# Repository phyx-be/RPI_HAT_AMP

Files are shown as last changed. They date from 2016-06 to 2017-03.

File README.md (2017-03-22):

# RPI HAT AMP TAS5756
A Class-D amplifier for your Raspberry Pi

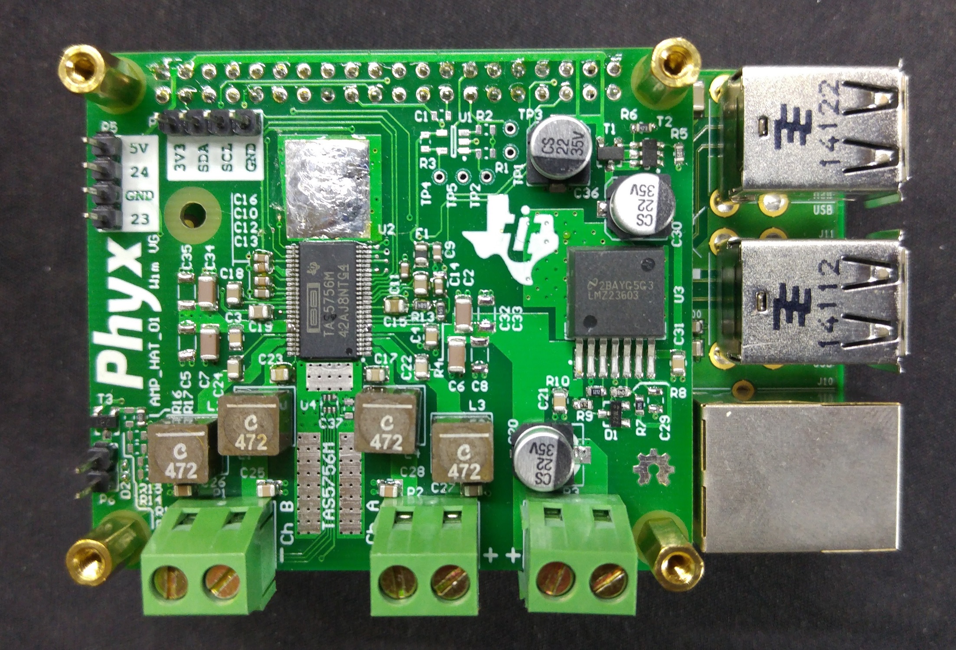
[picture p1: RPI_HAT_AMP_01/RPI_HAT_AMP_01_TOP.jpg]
Assembled image


## Rev 02

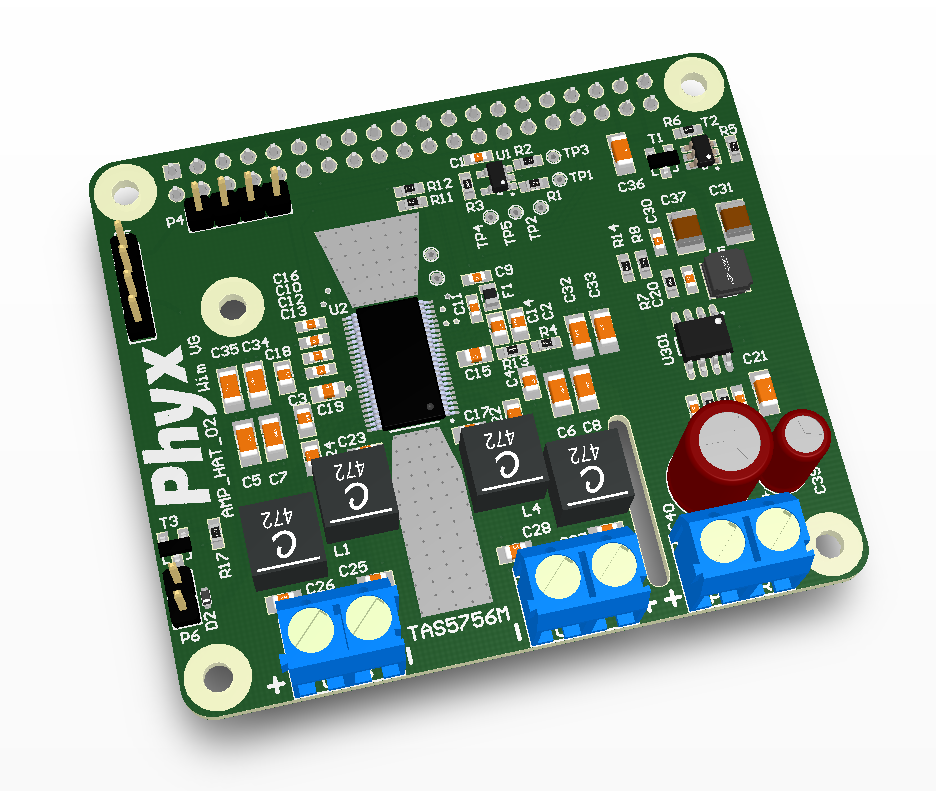
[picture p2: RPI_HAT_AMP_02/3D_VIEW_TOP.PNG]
RPI_HAT_AMP_02_TOP

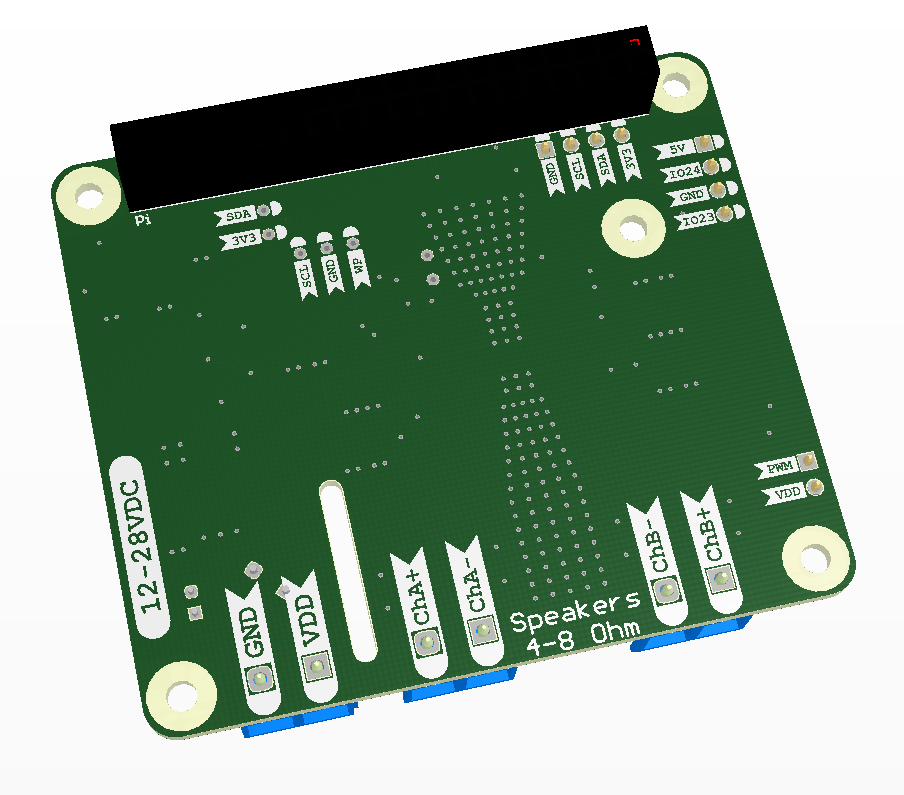
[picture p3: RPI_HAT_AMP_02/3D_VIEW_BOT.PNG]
RPI_HAT_AMP_02_BOT


Revision 02 has been updated with a [cheaper power supply](http://www.richtek.com/assets/product_file/RT7272A/DS7272A-04.pdf) with a wide input range.

## Rev 01

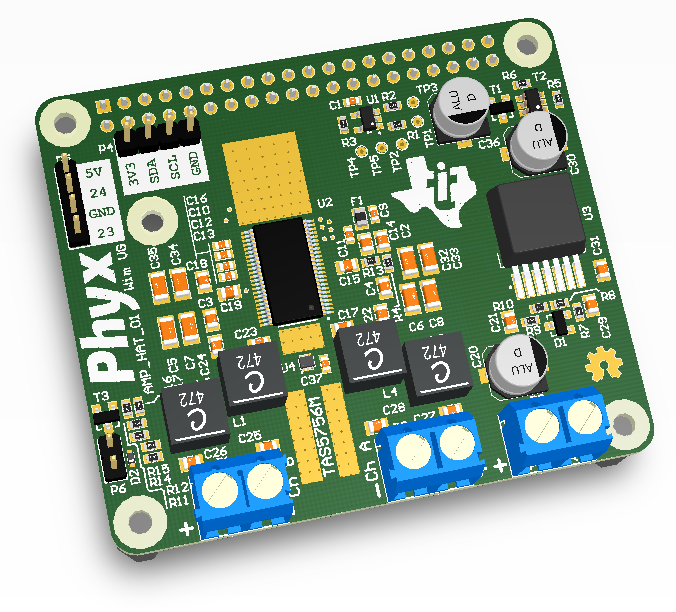
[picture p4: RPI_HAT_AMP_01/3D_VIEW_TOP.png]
RPI_HAT_AMP_01_TOP

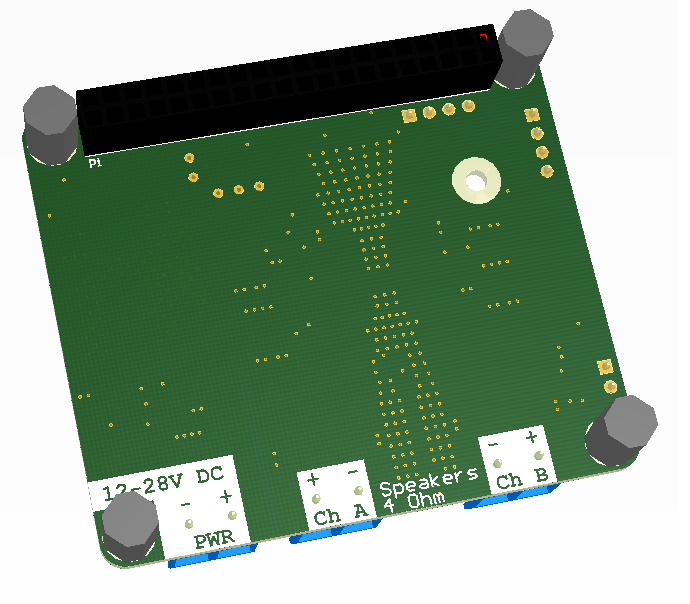
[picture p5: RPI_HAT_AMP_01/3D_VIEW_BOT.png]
RPI_HAT_AMP_01_BOT


The board is designed around the Ti [TAS5756](http://www.ti.com/product/TAS5756) Class D amplifier. It also features an I2C EEPROM, Ti [TMP112](http://www.ti.com/product/tmp112) I2C temperature sensor, some useful IO connectores, a FET connected to a PWM ouput and a Ti [LMZ23603](http://www.ti.com/product/LMZ23603) Simple Switcher module capable of providing 3A on the 5V rail.

### Possible improvements

- Cheaper Power supply
- Cheaper Inductors

## Setup your RPi

For our setup we use [Volumio](https://volumio.org) coupled with a little bit of Pyhton code to run everything. First things first, get yourself a running [Volumio](https://volumio.org) system by following [their manual](https://volumio.org/get-started/). Once the board is up and running you can start the configuration needed for the amplifier.
- Make sure your system is up to date by running `sudo rpi-update`
- Ensure the drivers are loaded by adding `dtoverlay=iqaudio-dacplus` in the `/boot/config.txt` file
- Remove the standard Raspberry Pi audio card by commecinting out the `snd-bcm2835` entry in the file `/etc/modules`, you might want to add `i2c-dev` as well.
- Sync and reboot your system wiht `sync` and `duso reboot`
- Verify your card is available to ALSO by running `aplay -l`
- Set the volume to 100% using `alsamixer`, both _ANALOGUE_ and _ANALOGUE PLAYBACK BOOST_ should be set to 100%
- Automaticly unmute the amplifier om boot by adding the following lines to `/etc/rc.local` right before `exit(0)`
```
#Unmute the AMP
echo "17" > /sys/class/gpio/export
echo "out" >/sys/class/gpio/gpio17/direction
echo "1" >/sys/class/gpio/gpio17/value
```
- Since the 5V power source is able to provide more than sufficient power to the board, you can increase the USB current of the Raspberry Pi. This can be done by adding `max_usb_current=1` to the `/boot/config.txt` file.

## Optional IO expansion

You can stack a PCB on the anplifier with 16 extra IO pins. This board is based on the [MCP23017](http://www.microchip.com/MCP23017) which is a 16 bits I2C IO expander. It has native support in [Wiring Pi](http://wiringpi.com/extensions/i2c-mcp23008-mcp23017/). You can stack more than one since the expander has multiple address pins. Just make sure you don't use the same address twice.

## Pictures

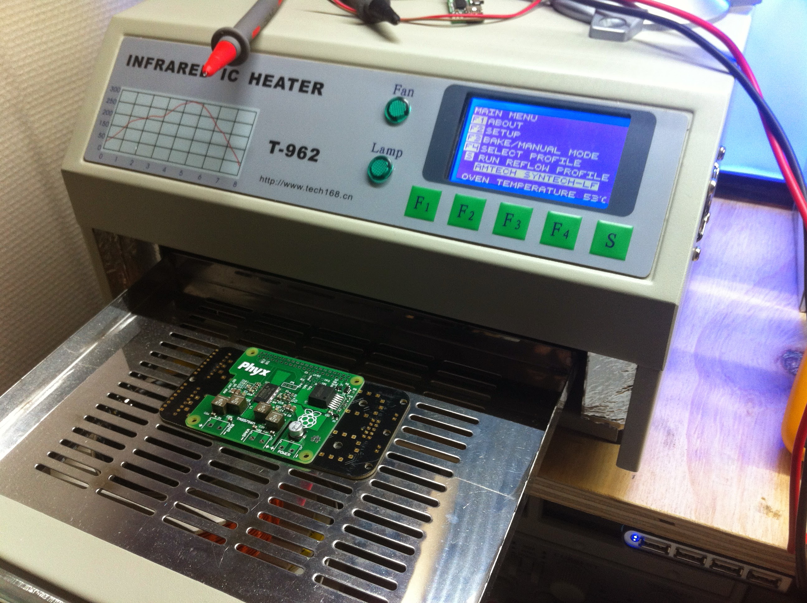
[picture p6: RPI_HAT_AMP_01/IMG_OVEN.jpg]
Oven image

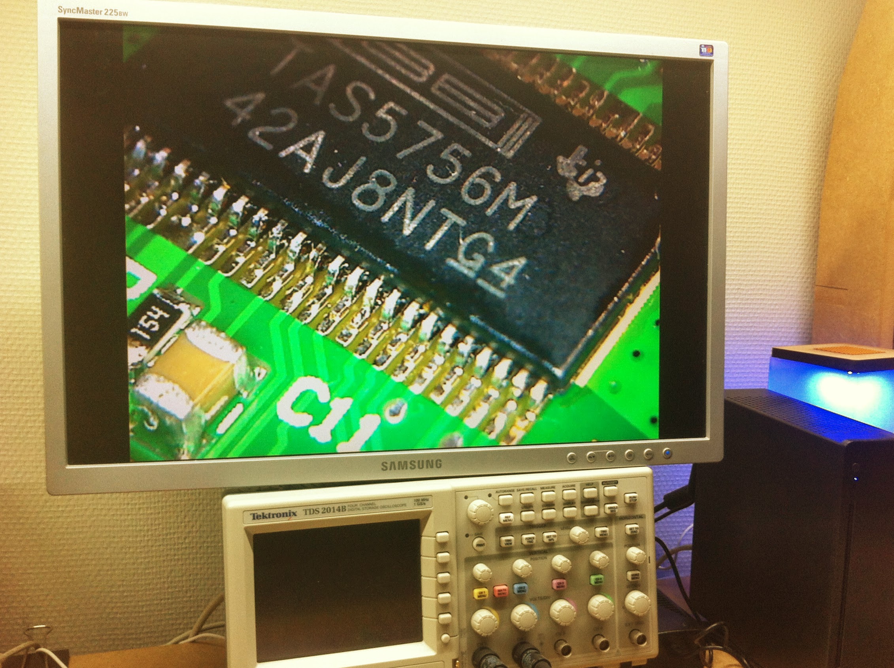
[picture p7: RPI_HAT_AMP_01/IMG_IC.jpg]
IC image


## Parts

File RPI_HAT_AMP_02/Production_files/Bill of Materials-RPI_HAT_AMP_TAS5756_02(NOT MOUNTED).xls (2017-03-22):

Bill of Materials |  |  | TAS5756 HAT
Project: |  | RPI_HAT_AMP_TAS5756_02.PrjPcb
Revision: |  | 02
Variant: |  | NOT MOUNTED
Creation Date: | 22/03/2017 | 20:34:39
Print Date: | 2017-03-22 | 20:36:30
Footprint | Comment | LibRef | Designator | Value | Description | Supplier 1 | Supplier Part Number 1 | Quantity
C0805_N | CAP_CERAMIC | CAP # 1uF 25V 0805 | C2 | 1uF 25V | Capacitor Ceramic | Farnell | 2395779 (https://octopart-clicks.com/click/altium?sku=2395779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) | 1
C0805_N | CAP_CERAMIC | CAP # 100nF 50V 0805 | C3, C4 | 100nF 50V | Capacitor Ceramic | Farnell | 1759265 (https://octopart-clicks.com/click/altium?sku=1759265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) | 2
C1206_N | CAP_CERAMIC | CAP # 22uF 35V 1206 X5R | C5, C6, C7, C8, C32, C33, C34, C35, C36 | 22uF 35V | Capacitor Ceramic | Digikey | 445-8045-1-ND (https://octopart-clicks.com/click/altium?sku=445-8045-1-ND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) | 9
C0603_N | CAP_CERAMIC | CAP # 1uF 16V 0603 | C9, C10, C11, C12, C13, C16 | 1uF 16V | Capacitor Ceramic | Farnell | 2320814 (https://octopart-clicks.com/click/altium?sku=2320814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) | 6
C0805_N | CAP_CERAMIC | CAP # 2u2F 25V 0805 | C14, C15, C18, C19 | 2u2F | Capacitor Ceramic | Farnell | 2320829 (https://octopart-clicks.com/click/altium?sku=2320829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) | 4
C0805_N | CAP_CERAMIC | CAP # 220nF 50V 0805 | C17, C22, C23, C24 | 220nF 50V | Capacitor Ceramic | Farnell | 2320842 (https://octopart-clicks.com/click/altium?sku=2320842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) | 4
C0603_N | CAP_CERAMIC | CAP # 100nF 50V 0603 | C20, C30 | 100nF 50V | Capacitor Ceramic | Farnell | 1759122 (https://octopart-clicks.com/click/altium?sku=1759122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) | 2
C1206_N | CAP_CERAMIC | CAP # 10uF 35V 1206 X5R | C21 | 10uF 35V | Capacitor Ceramic | Farnell | 1797011 (https://octopart-clicks.com/click/altium?sku=1797011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) | 1
C0805_N | CAP_CERAMIC | CAP # 680nF 50V 0805 | C25, C26, C27, C28 | 680nF 50V | Capacitor Ceramic | Farnell | 2210987 (https://octopart-clicks.com/click/altium?sku=2210987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) | 4
C1210_N | CAP_CERAMIC | CAP # 22uF 10V 1210 X5R | C31, C37 | 22uF 10V | Capacitor Ceramic |  |  | 2
C0603_N | CAP_CERAMIC | CAP # 2n7F 25V 0603 | C38 | 2n7F 25V | Capacitor Ceramic |  |  | 1
ON_SOD-523 | NSR0240V2T1G Schottky ULTRAFAST, 200MA, 40V | Schottky NSR0240V2T1G | D2 | NSR0240V2T1G |  | Farnell | 2317403 (https://octopart-clicks.com/click/altium?sku=2317403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) | 1
L0805 | FERRITE | FER # 120R 0.8A 0805 0R12 | F1 | 0.8A 0R12 |  | Farnell | 1669728 (https://octopart-clicks.com/click/altium?sku=1669728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) | 1
XAL6060-472 | XAL6060-472MEC | IND # 4u7H 11A | L1, L2, L3, L4 | 4u7H 11A |  | Farnell | 2289085 (https://octopart-clicks.com/click/altium?sku=2289085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) | 4
SNL_SWPA4020 | SWPA4020S6R8MT | IND # 6u8H SWPA4020 | L5 | 6u8H |  | China | SWPA4020S6R8MT (https://octopart-clicks.com/click/altium?manufacturer=Supplier%20disabled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) | 1
TERM_BLK-0508-2-90 | 2 Way Screw HDR 5,08mm | Terminal Block 5,08mm 2way | P1, P2, P3 | PM5.08/2/90 |  | Farnell |  | 3
HDR1X4 | Header 4 | Pin Header 2.54mm 4way | P5 |  |  |  |  | 1
HDR1X2 | Header 2 | Pin Header 2.54mm 2way | P6 |  |  |  |  | 1
RCPT2X20 | Header 20X2 | Receptable 2.54mm dual row 40way | Pi |  |  |  |  | 1
R0603_N | RESISTOR | RES # 150K 0603 | R4 | 150K |  |  |  | 1
R0603_N | RESISTOR | RES # 10K 0603 | R5 | 10K |  |  |  | 1
R0603_N | RESISTOR | RES # 47K 0603 | R6 | 47K |  |  |  | 1
R0603_N | RESISTOR | RES # 100K 0603 | R7 | 100K |  |  |  | 1
R0603_N | RESISTOR | RES # 62K 0603 | R8 | 62K |  |  |  | 1
R0603_N | RESISTOR | RES # 24K 0603 | R9 | 24K |  |  |  | 1
R0603_N | RESISTOR | RES # 180K 0603 | R10 | 180K |  |  |  | 1
R0603_N | RESISTOR | RES # 680K 0603 | R13 | 680K |  |  |  | 1
R0603_N | RESISTOR | RES # 11K8 0603 | R14 | 11K8 |  |  |  | 1
R0603_N | RESISTOR | RES # 0R 0603 | R17 | 0R |  |  |  | 1
SOT23-3 | 4A P-Ch MOSFET Vgs -4,5 | TSM2311CX P-Ch MOSFET 4A | T1 | TSM2311CX |  | Farnell | 1864586 (https://octopart-clicks.com/click/altium?sku=1864586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) | 1
SOT23-6 | Matched PNP | DMMT5401-7-F matched PNP | T2 | DMMT5401-7-F |  | Farnell | 1773583 (https://octopart-clicks.com/click/altium?sku=1773583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) | 1
SOT23-3 | 2.4A N-Ch MOSFET Vgs 4.5 | ZXMN2B01F N-Ch MOSFET 2.4A 4.5Vgs 30Vds | T3 | ZXMN2B01F |  | Farnell | 1426253 (https://octopart-clicks.com/click/altium?sku=1426253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) | 1
TI-DCA-R-PDSO-G48 | Audio Amp Class D 2ch 2x40W - 1x75W 104SNR | AMP # AUD TAS5756M | U2 | TAS5756M |  |  |  | 1
SOIC_N_8_TH | Buck 3A 36Vin sync | PWR # Buck RT7272A SOP8 | U301 | RT7272AGSP |  | China | RT7272AGSP (https://octopart-clicks.com/click/altium?sku=RT7272AGSP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) | 1
 |  |  |  |  |  |  |  | 64
Approved |  | Notes

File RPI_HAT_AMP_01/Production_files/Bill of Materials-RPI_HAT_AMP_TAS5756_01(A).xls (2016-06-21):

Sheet: BOM Report
Bill of Materials |  |  | Variant [A] of [RPI_HAT_AMP_TAS5756_01]
Source Data From: |  | RPI_HAT_AMP_TAS5756_01.PrjPcb
Project: |  | RPI_HAT_AMP_TAS5756_01.PrjPcb
Variant: |  | A
Creation Date: | 29/08/2015 | 22:58:33
Print Date: | 42542 | 42542.93206
Footprint | Comment | LibRef | Designator | Value | Description | Supplier 1 | Supplier Part Number 1 | Quantity
C0603 | CAP_CERAMIC | CAP # 100nF 16V 0603 | C1, C37 | 100nF 16V | Capacitor Ceramic |  |  | 2
C0805 | CAP_CERAMIC | CAP # 1uF 25V 0805 | C2 | 1uF 25V | Capacitor Ceramic | Farnell | 2395779 | 1
C0805 | CAP_CERAMIC | CAP # 100nF 50V 0805 | C3, C4, C21, C31 | 100nF 50V | Capacitor Ceramic | Farnell | 1759265 | 4
C1206 | CAP_CERAMIC | CAP # 22uF 35V 1206 X5R | C5, C6, C7, C8, C32, C33, C34, C35 | 22uF 35V | Capacitor Ceramic | Digikey | 445-8045-1-ND | 8
C0603 | CAP_CERAMIC | CAP # 1uF 16V 0603 | C9, C10, C11, C12, C13, C16 | 1uF 16V | Capacitor Ceramic | Farnell | 2320814 | 6
C0805 | CAP_CERAMIC | CAP # 2u2F 25V 0805 | C14, C15, C18, C19 | 2u2F | Capacitor Ceramic | Farnell | 2320829 | 4
C0805 | CAP_CERAMIC | CAP # 220nF 50V 0805 | C17, C22, C23, C24 | 220nF 50V | Capacitor Ceramic | Farnell | 2320842 | 4
C6.6x5.4 | CAP_POL | CAP # 22uF 35V 6mm3 | C20, C30, C36 | 22uF 35V | Capacitor electrolyt | Farnell | 9265724 | 3
C0805 | CAP_CERAMIC | CAP # 680nF 50V 0805 | C25, C26, C27, C28 | 680nF 50V | Capacitor Ceramic | Farnell | 2210987 | 4
SOT23-3 | 5.1V Zener 250mW | Zen # BZX84 5V1 | D1 | BZX84-C5V1 | Default Diode | Farnell | 1081430 | 1
ON_SOD-523 | NSR0240V2T1G Schottky ULTRAFAST, 200MA, 40V | Schottky NSR0240V2T1G | D2 | NSR0240V2T1G | =Description | Farnell | 2317403 | 1
L0805 | FERRITE | FER # 120R 0.8A 0805 0R12 | F1 | 0.8A 0R12 |  | Farnell | 1669728 | 1
XAL6060-472 | XAL6060-472MEC | IND # 4u7H 11A | L1, L2, L3, L4 | 4u7H 11A |  | Farnell | 2289085 | 4
TERM_BLK-0508-2-90 | 2 Way Screw HDR 5,08mm | Terminal Block 5,08mm 2way | P1, P2, P3 | PM5.08/2/90 |  | Farnell |  | 3
HDR1X4 | Header 4 | Pin Header 2.54mm 4way | P4, P5 |  |  |  |  | 2
HDR1X2 | Header 2 | Pin Header 2.54mm 2way | P6 |  |  |  |  | 1
RCPT2X20 | Header 20X2 | Receptable 2.54mm dual row 40way | Pi |  | =Description |  |  | 1
R0603 | RESISTOR | RES # 3K9 0603 | R1, R2, R14 | 3K9 |  |  |  | 3
R0603 | RESISTOR | RES # 1K 0603 | R3 | 1K |  |  |  | 1
R0603 | RESISTOR | RES # 150K 0603 | R4 | 150K |  |  |  | 1
R0603 | RESISTOR | RES # 10K 0603 | R5 | 10K |  |  |  | 1
R0603 | RESISTOR | RES # 47K 0603 | R6 | 47K |  |  |  | 1
R0603 | RESISTOR | RES # 5K62 0603 | R7 | 5K62 |  | Farnell | 2138405 | 1
R0603 | RESISTOR | RES # 1K07 0603 | R8 | 1K07 |  | Farnell | 2073360 | 1
R0603 | RESISTOR | RES # 42K2 0603 | R9 | 42K2 |  | Farnell | 2073498 | 1
R0603 | RESISTOR | RES # 12K7 0603 | R10 | 12K7 |  | Farnell | 2138428 | 1
R0603 | RESISTOR | RES # 680K 0603 | R13 | 680K |  |  |  | 1
R0603 | RESISTOR | RES # 0R 0603 | R15, R17 | 0R |  |  |  | 2
SOT23-3 | 4A P-Ch MOSFET Vgs -4,5 | TSM2311CX P-Ch MOSFET 4A | T1 | TSM2311CX | =Description | Farnell | 1864586 | 1
SOT23-6 | Matched PNP | DMMT5401-7-F matched PNP | T2 | DMMT5401-7-F |  | Farnell | 1773583 | 1
SOT23-3 | 2.4A N-Ch MOSFET Vgs 4.5 | ZXMN2B01F N-Ch MOSFET 2.4A 4.5Vgs 30Vds | T3 | ZXMN2B01F |  | Farnell | 1426253 | 1
TP_0.4mm | TEST_PAD | TP # 0.4mm | TP14 | NO BOM |  |  |  | 1
SOT23-5 | Serial EEPROM 64K (8b) SOT35 I2C | EEPROM # I2C 8Kx8b 24LC64T-I/OT | U1 | 24LC64T-I/OT | =Description | Farnell | 1700992 | 1
TI-DCA-R-PDSO-G48 | Audio Amp Class D 2ch 2x40W - 1x75W 104SNR | AMP # AUD TAS5756M | U2 | TAS5756M | =Description |  |  | 1
7TO-PMOD | 0.8V-6V 3A 36Vin | PWR # MOD LMZ23603 3A | U3 | LMZ23603 | =Description | Farnell | 1890061 | 1
TI_DRL_R-PDSO-N6 | I2C Temp sensor High Accuracy | TEMP # TMP112 | U4 | TMP112 | =Description | Farnell | 1735574 | 1
 |  |  |  |  |  |  |  | 72
Approved |  | Notes

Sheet: Project Information
Project Full Path | C:\Users\WimVG\Dropbox\Electronics\RPI_HAT_AMP\RPI_HAT_AMP_TAS5756_01.PrjPcb
Project Filename | RPI_HAT_AMP_TAS5756_01.PrjPcb
Variant Name | A
Data-Source Filename | RPI_HAT_AMP_TAS5756_01.PrjPcb
Data-Source Full Path | C:\Users\WimVG\Dropbox\Electronics\RPI_HAT_AMP\RPI_HAT_AMP_TAS5756_01.PrjPcb
Title | Bill of Materials For Variant [A] of Project [RPI_HAT_AMP_TAS5756_01.PrjPcb] (No PCB Document Selected)
Total Quantity | 72
Report Time | 22:58:33
Report Date | 29/08/2015
Report Date & Tine | 29/08/2015 22:58:33
Output Name | Bill of Materials
Output Type | BOM_PartType
Output Generator Name | BOM
Output Generator Description | Bill of Materials

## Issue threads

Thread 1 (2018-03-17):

Headphones

renne, 2018-03-17:
Hi,

it's a great circuit!
I suggest to connect a headphone amplifier to DAC_OUTA/B.

renne, 2018-03-27:
Alternatively an I2S headphone DAC can be used. This allows to connect the I2S headphone DAC in parallel on hosts with one I2C-bus (e.g. RPi) or connect it independently on devices with two I2S-busses (e.g. [Expressif ESP32](https://github.com/phyx-be/RPI_HAT_AMP/issues/6)).

renne, 2018-03-28:
I suggest to have a look at the [TI TPA6130A2 Stereo Headphone Amplifier](http://www.ti.com/product/TPA6130A2/technicaldocuments).

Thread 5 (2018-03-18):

Add two I2S MEMS microphones

renne, 2018-03-18:
Please add two I2S MEMS microphones (e.g. [Knowles SPH0645LM4H-B](http://www.knowles.com/kor/content/download/5988/105771/version/4/file/SPH0645LM4H-BRevB.PDF)) for far field usage to the layout (e.g. voice control, hands-free applications).

renne, 2018-03-27:
In case of a host with two I2S-busses (e.g. [Expressif ESP32](https://github.com/phyx-be/RPI_HAT_AMP/issues/6)) four microphones can be used to improve spatial noise filtering.

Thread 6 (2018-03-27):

Support Expressif ESP32

renne, 2018-03-27:
The Raspberry Pi is a great device if you need a full blown Linux operating system. If you just want WLAN-/Bluetooth audio streaming and some logic operations the [Expressif ESP32](https://en.wikipedia.org/wiki/ESP32) is much more power efficient and cheaper. It also has two I2S busses.

I suggest to add pin headers for [surface-mount ESP32 module boards](https://en.wikipedia.org/wiki/ESP32#Surface-mount_module_boards).

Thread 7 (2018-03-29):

Support multiple I2C adresses

renne, 2018-03-29:
Support the use of multiple I2C-addresses (e.g. BiAmp-stacking or conflicts with other devices) by adding jumpers or DIP-switches to ADR0 and ADR1.

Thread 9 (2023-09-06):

Problem to start up the amp

iOsnaaente, 2023-09-06:
Hello. Recently I designed an TAS5756M board to use as an amplifier, but when a power up the board, nothing worked. I am reading in foruns what was happened, but unfortunately I didn't found anything about the TAS boot configurations. Reading about your project, I believe that we are on the same page, so I should know if you could help me taking a few questions about the my project :D

Sorry about my english, I am a Braziliam guy :D

iOsnaaente, 2023-09-06:
Oh, you may send me an email: bruno.bielsam.1205@hotmail.com
if it is not a problem for you, of course :D

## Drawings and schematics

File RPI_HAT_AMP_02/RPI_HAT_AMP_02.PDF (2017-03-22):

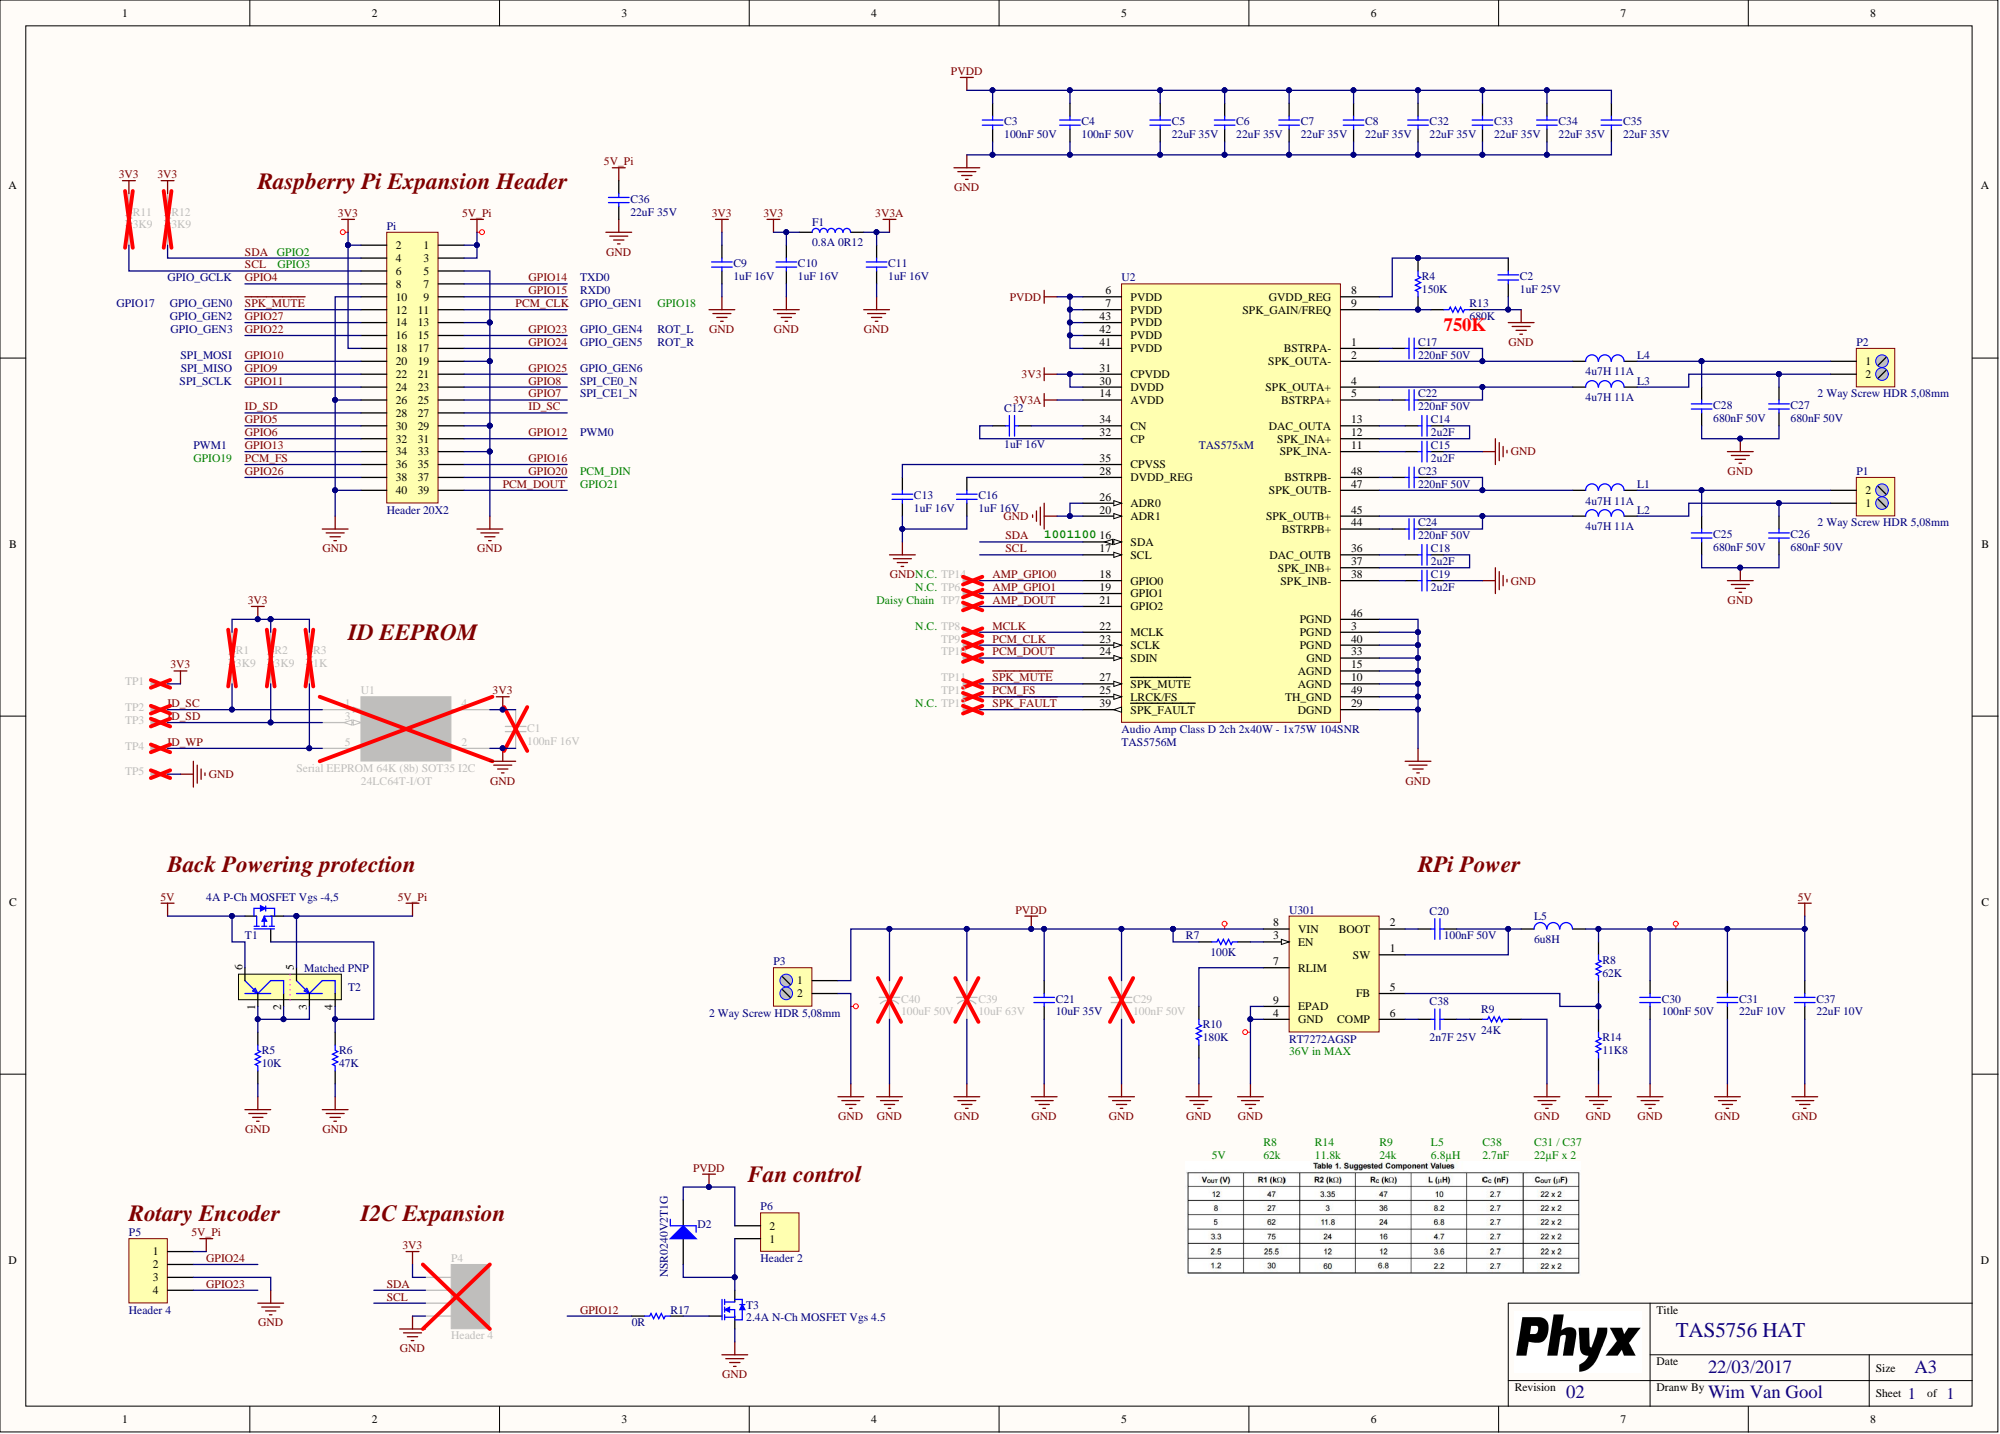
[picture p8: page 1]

Raspberry Pi Expansion Header

DVDD_REG 28

ADR1 20

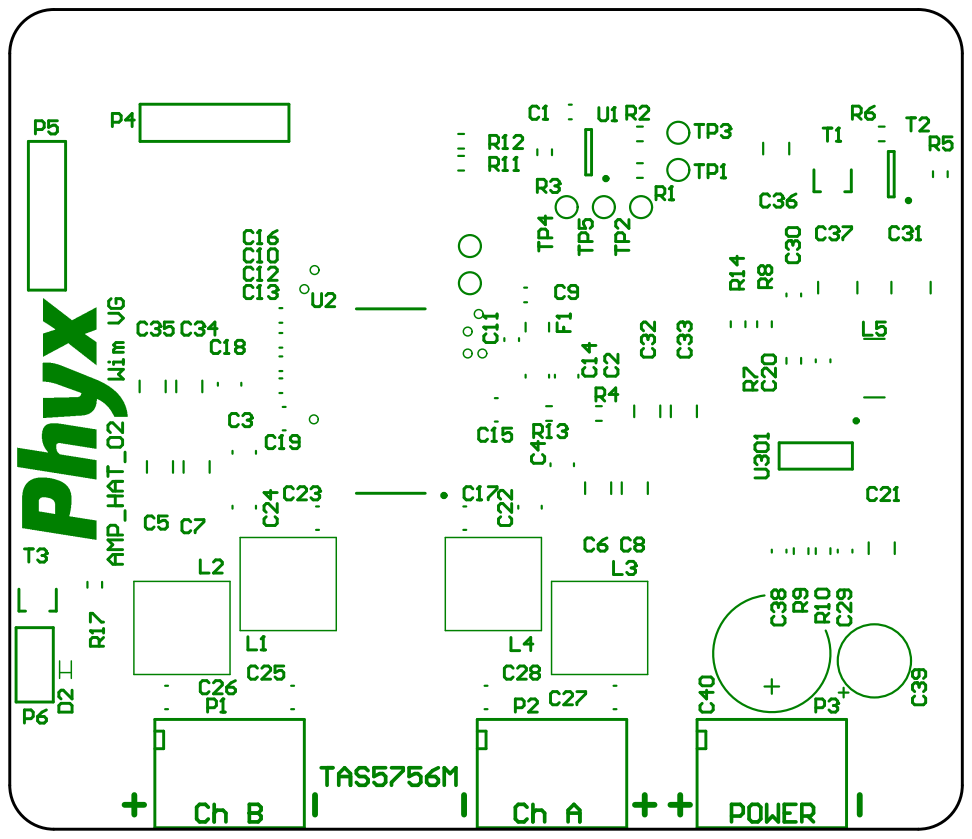
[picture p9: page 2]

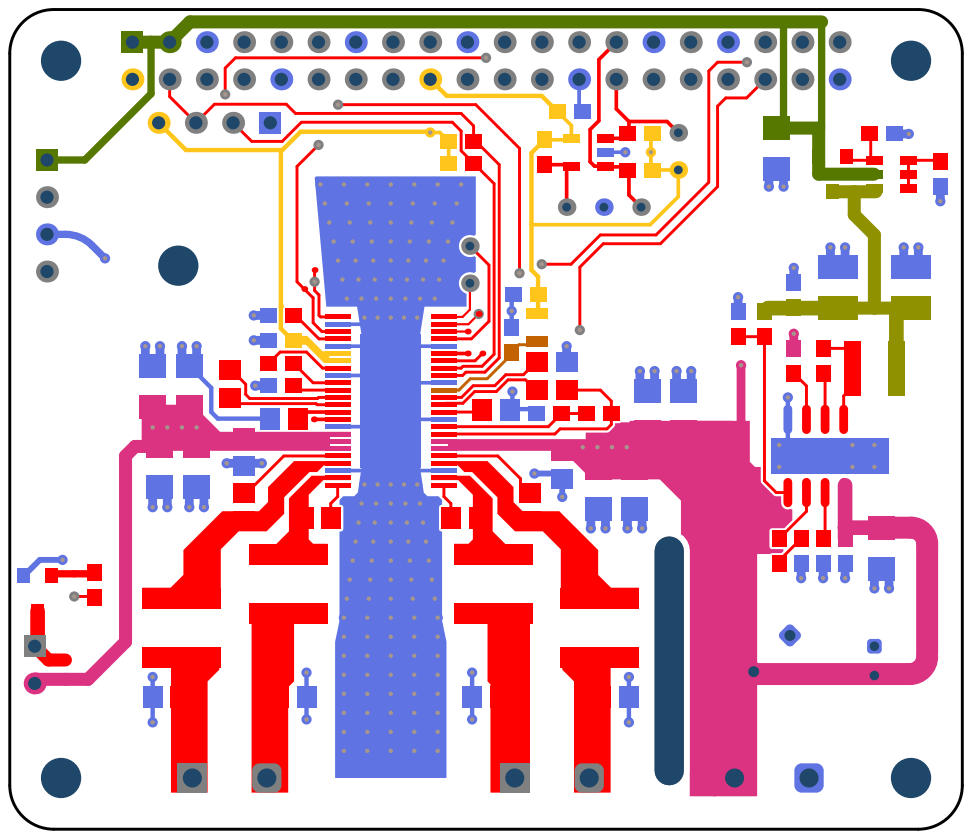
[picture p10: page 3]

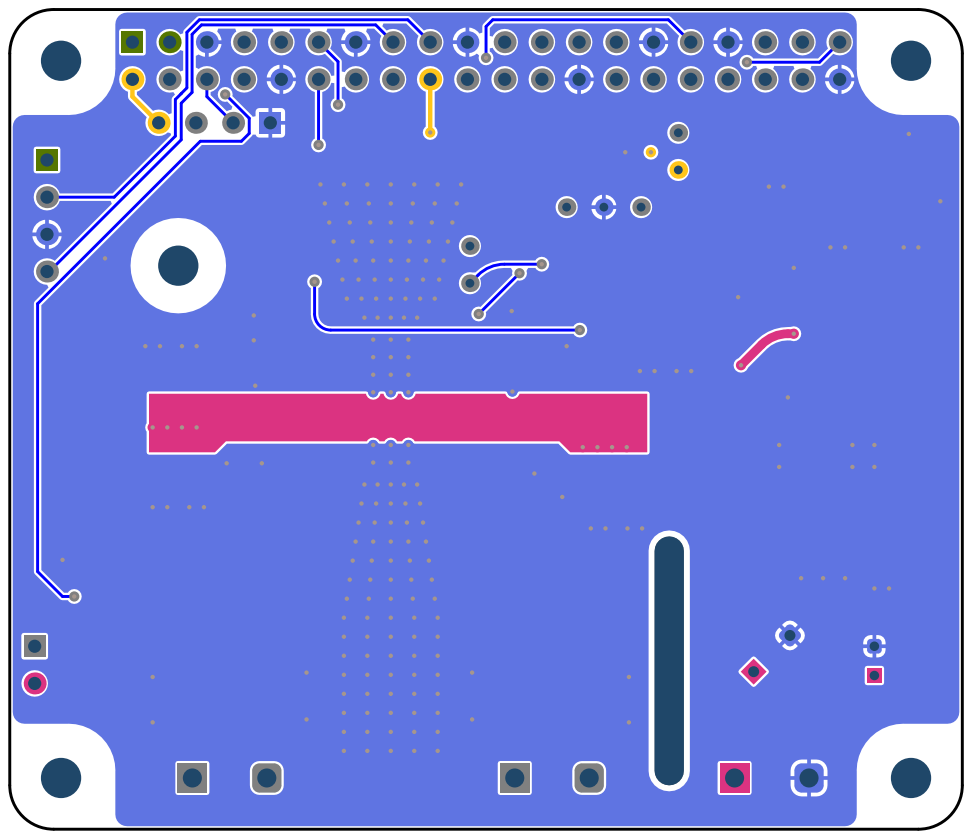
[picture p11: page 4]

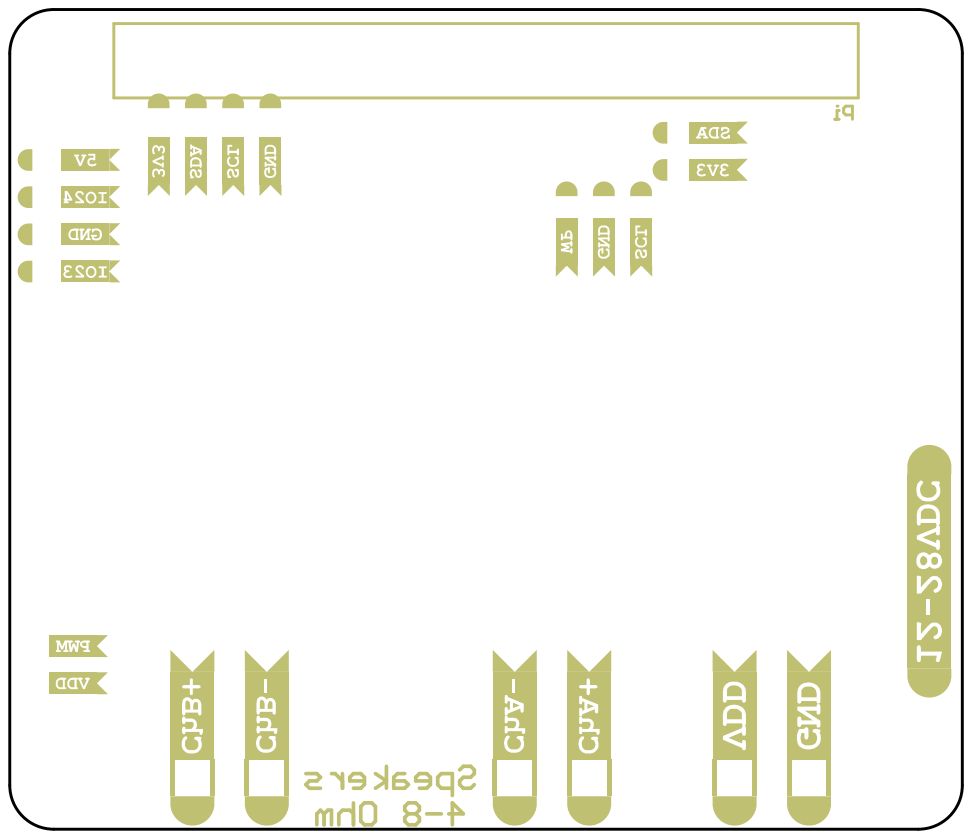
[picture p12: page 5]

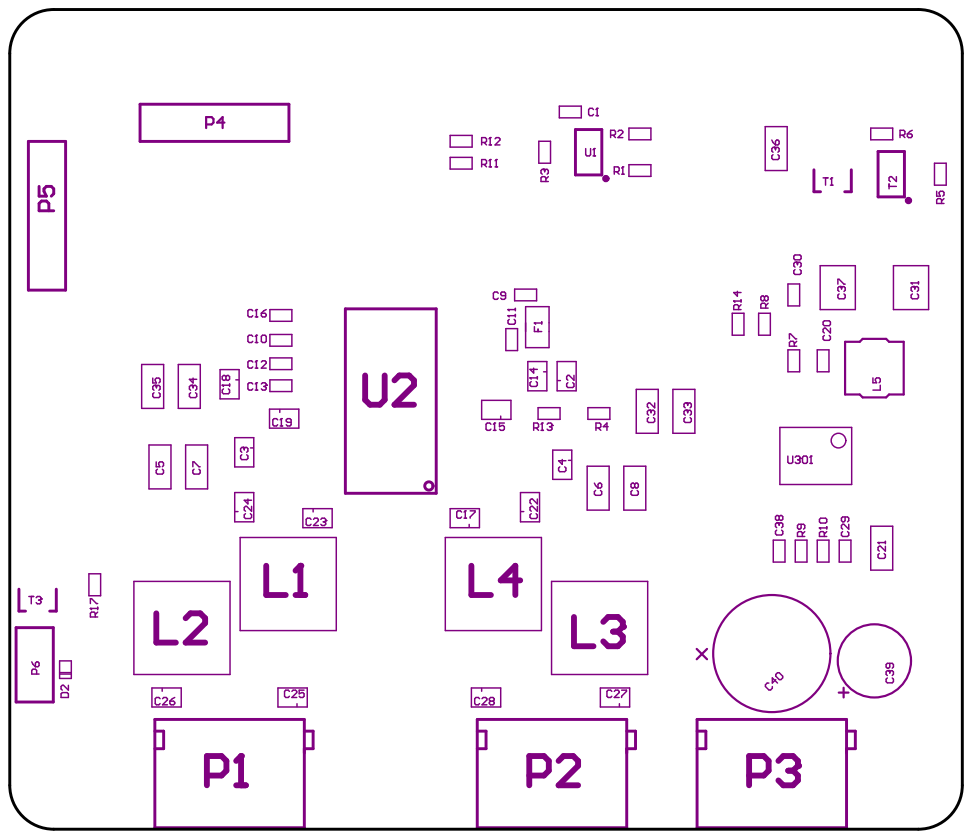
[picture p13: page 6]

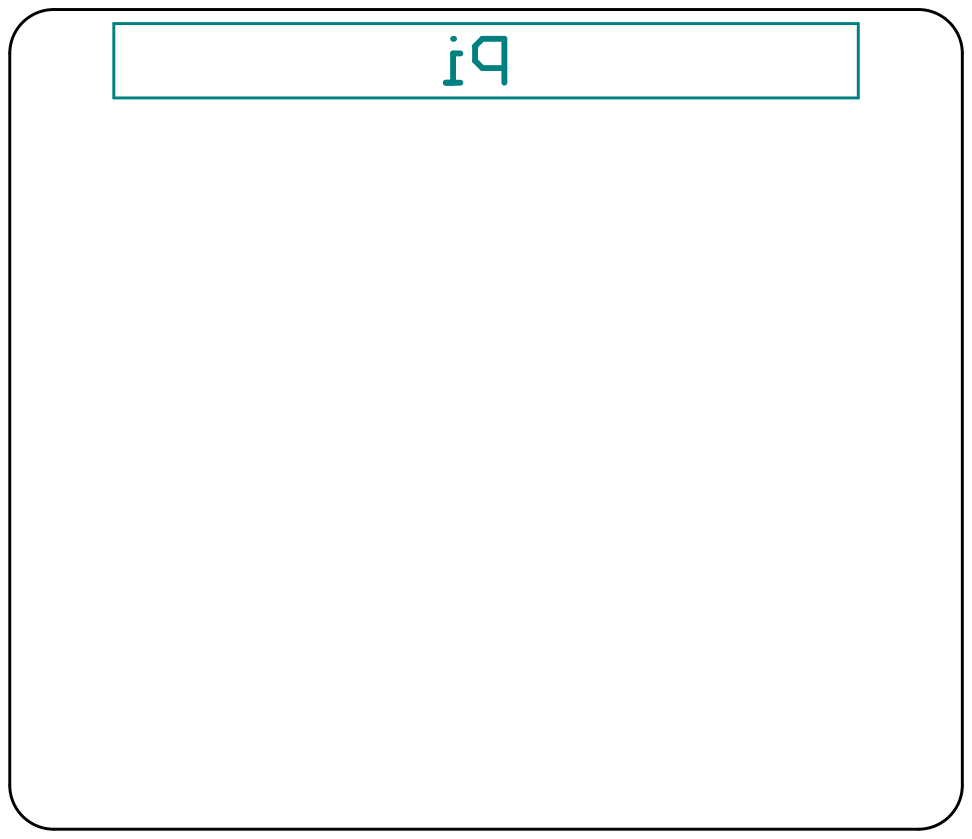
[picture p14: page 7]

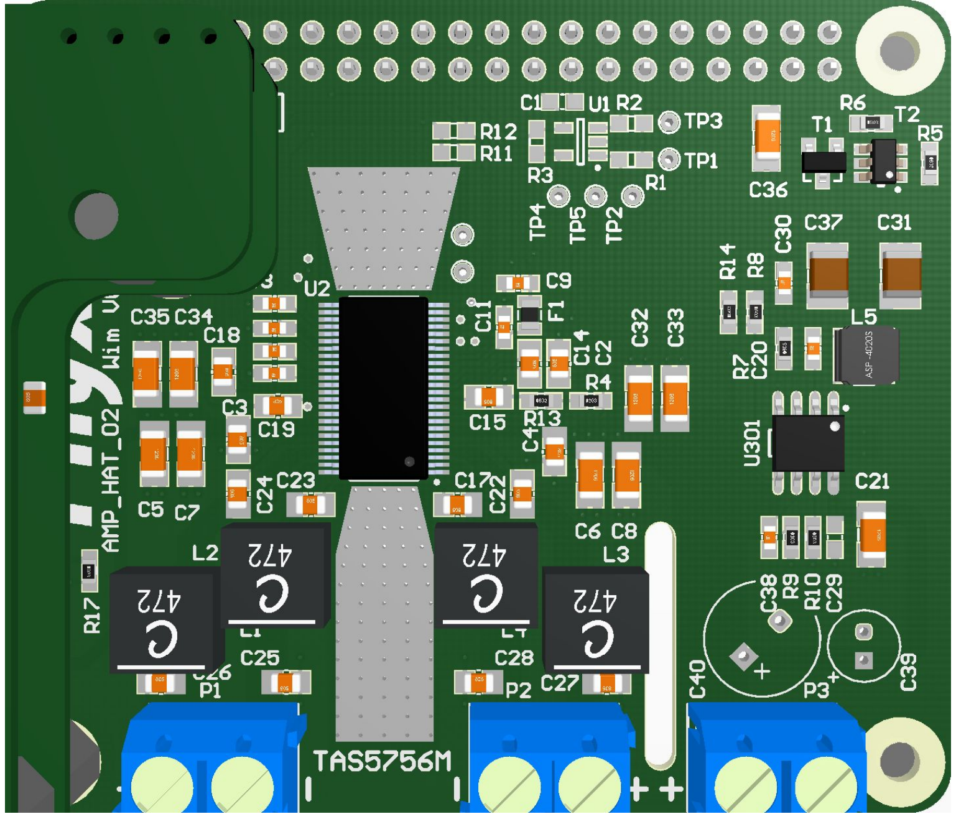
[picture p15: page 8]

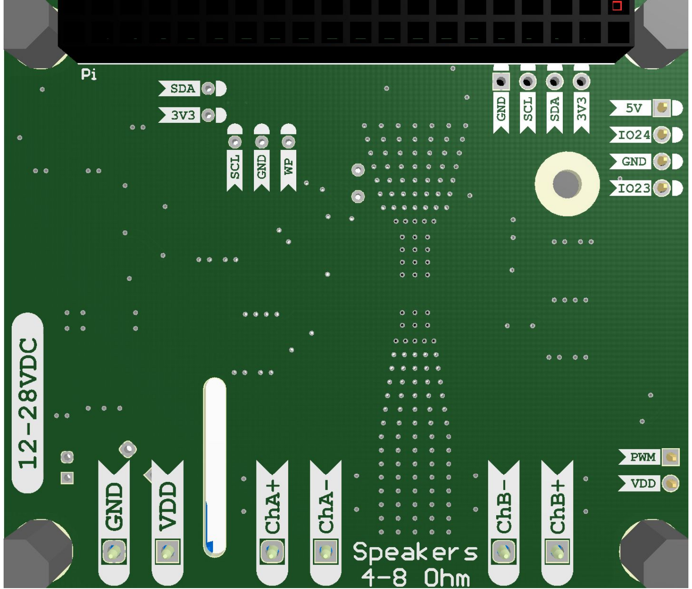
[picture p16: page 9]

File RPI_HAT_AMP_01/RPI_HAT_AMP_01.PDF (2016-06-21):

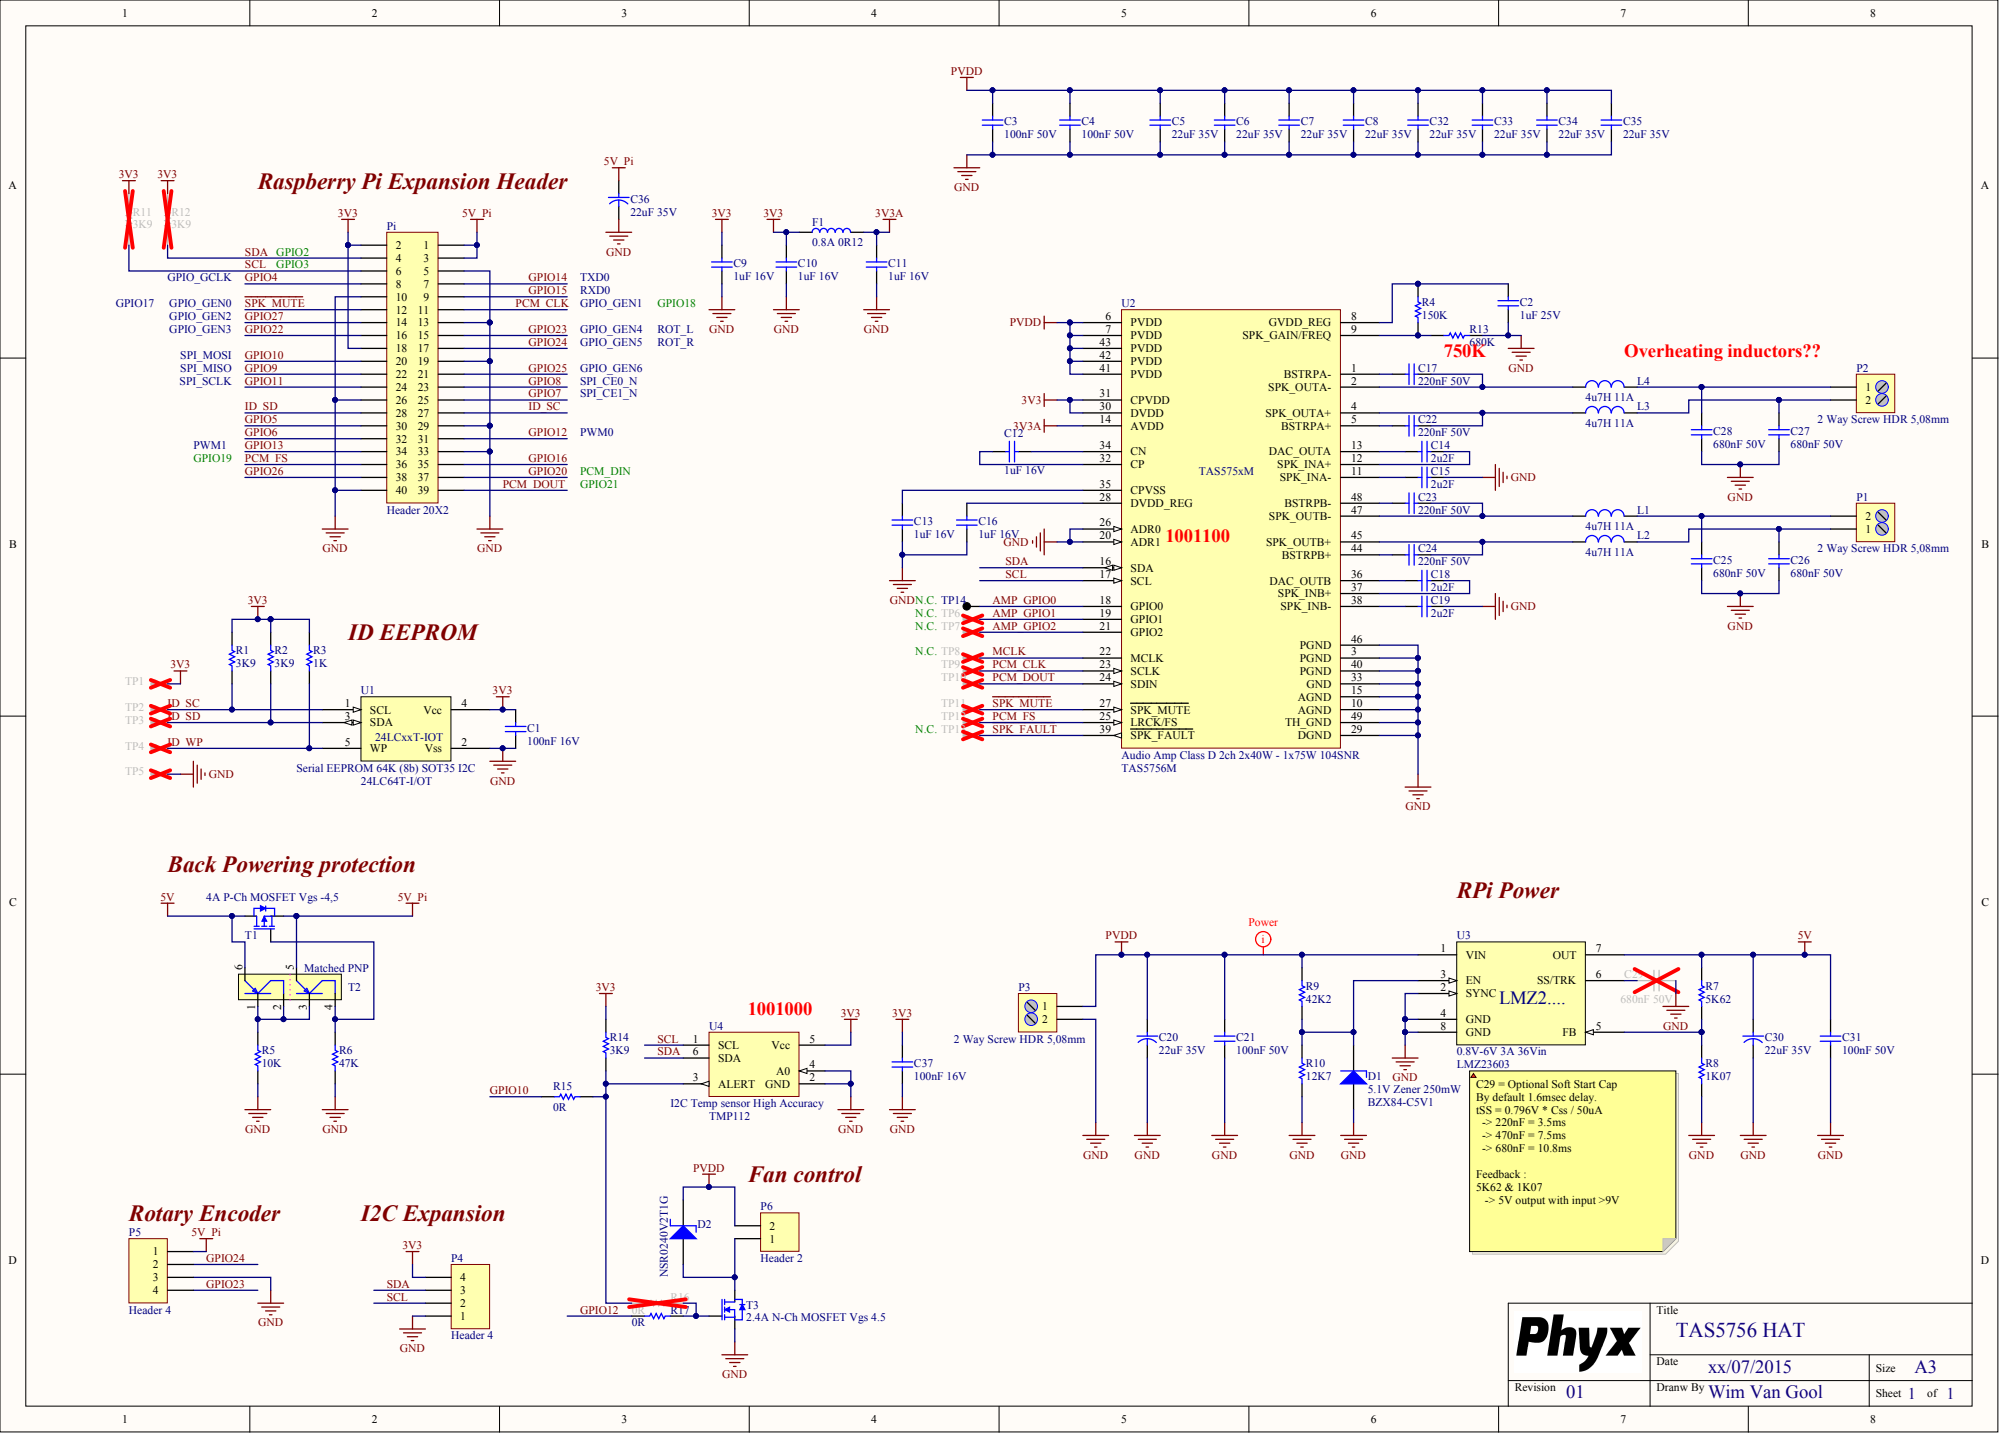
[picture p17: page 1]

Raspberry Pi Expansion Header

DVDD 30
AVDD 14 | C22

I2C Temp sensor High Accuracy

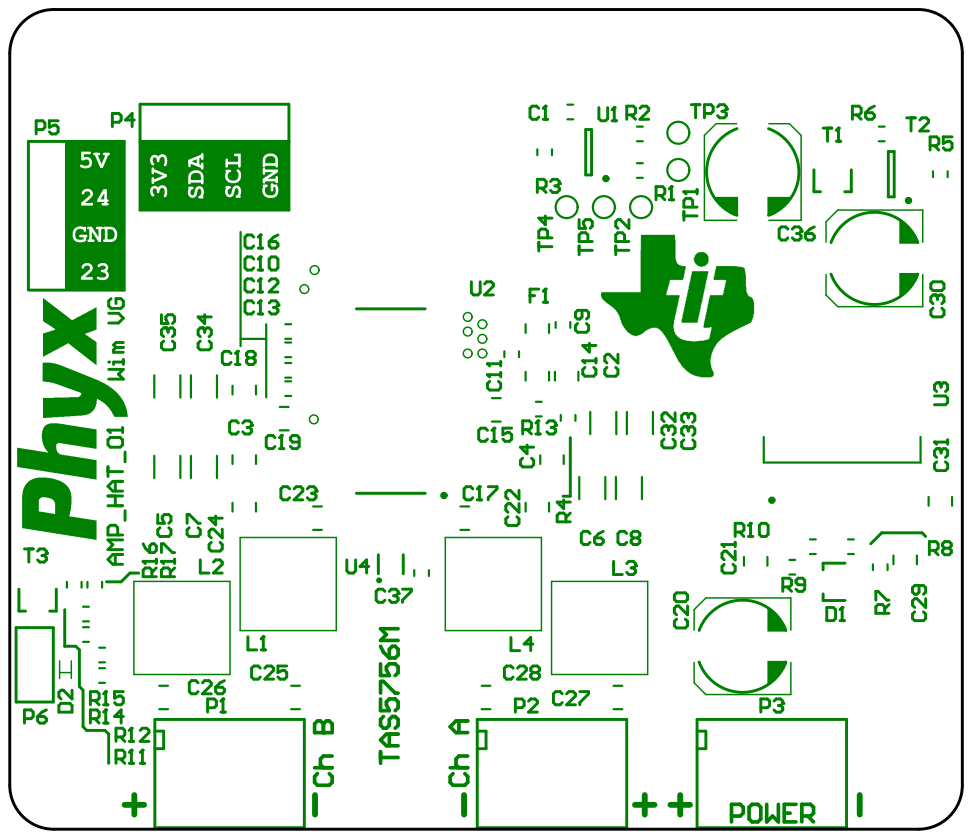
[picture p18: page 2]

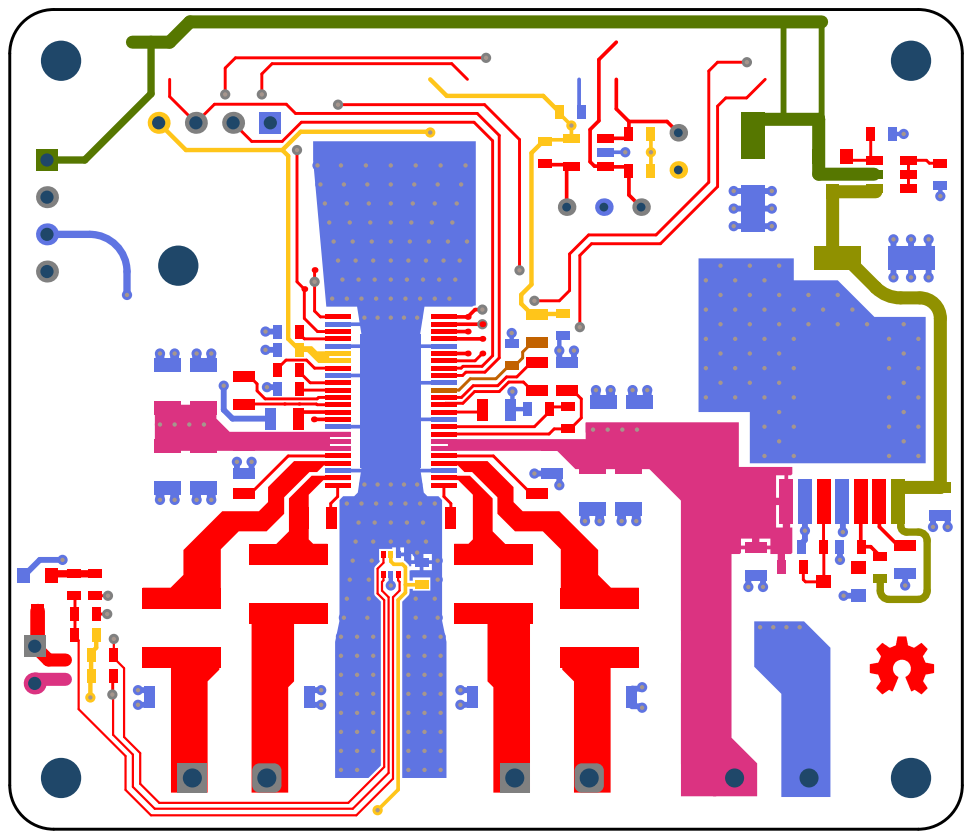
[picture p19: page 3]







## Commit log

2016-06-21 inital commit
    design files added for rev 01
    [Bill of Materials-RPI_HAT_AMP_TAS5756_01(A).xls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]
2016-07-05 Config info
    More configuration information added, also added photo of assembled
    board
2017-03-22 Revision 02 added
    New revision files added
    [Bill of Materials-RPI_HAT_AMP_TAS5756_02(NOT MOUNTED).xls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]
2017-03-22 Assembly drawing cleanup
